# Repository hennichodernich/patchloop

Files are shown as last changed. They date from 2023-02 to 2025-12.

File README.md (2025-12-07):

# patchloop
Design files for the PatchLoop PCB

The files patchloop2.kicad_* contain the version with RJ45 jacks on opposite sides. This allows for neat short traces between the jacks.

I needed to rework the files patchloop.kicad_* (jacks on same side) because the first version contained a bug so that only one loop was used effectively.

PCB manufacturer Aisler will directly accept the KiCad file for manufacturing, but you can find zipfiles with the gerbers for both variants in the gerbers/ subdirectory. Any PCB manufacturer (e.g. BetaLayout, JLCPCB, PCBWay, OSHPark) should be able to accept those.

Licensed under CC BY-SA 3.0

# Note on the choice of balun

While in the schematic (and in the BOM) you will find an M/A-COM ETC4-1-2, this might not be the optimal choice for all possible patch cables. For cables with a length of 2-3 meters, an ETC1-1-13 usually works better to achieve ~50 ohms on the coax connector. The ETC4-1-2 is advantageous for very long cables (and thus higher impedances). I also tried Coilcraft WBC4-4 to transform from very low impedances to 50 ohms (take care of its orientation), but this only makes sense for very short cables: A 1m cable exposed approximately 10 ohms to my NanoVNA.

In general the same holds for selfwound baluns, an 1:1 balun will work best in most of your applications. For instance, I found 2:2 turns on a 9ct Fair-Rite 2843002402 binocular core working well.

Best overall performance including VLF and LF showed a M/A-COM ETC1-1T-2TR combined with 2m of S/FTP Cat6 cable.

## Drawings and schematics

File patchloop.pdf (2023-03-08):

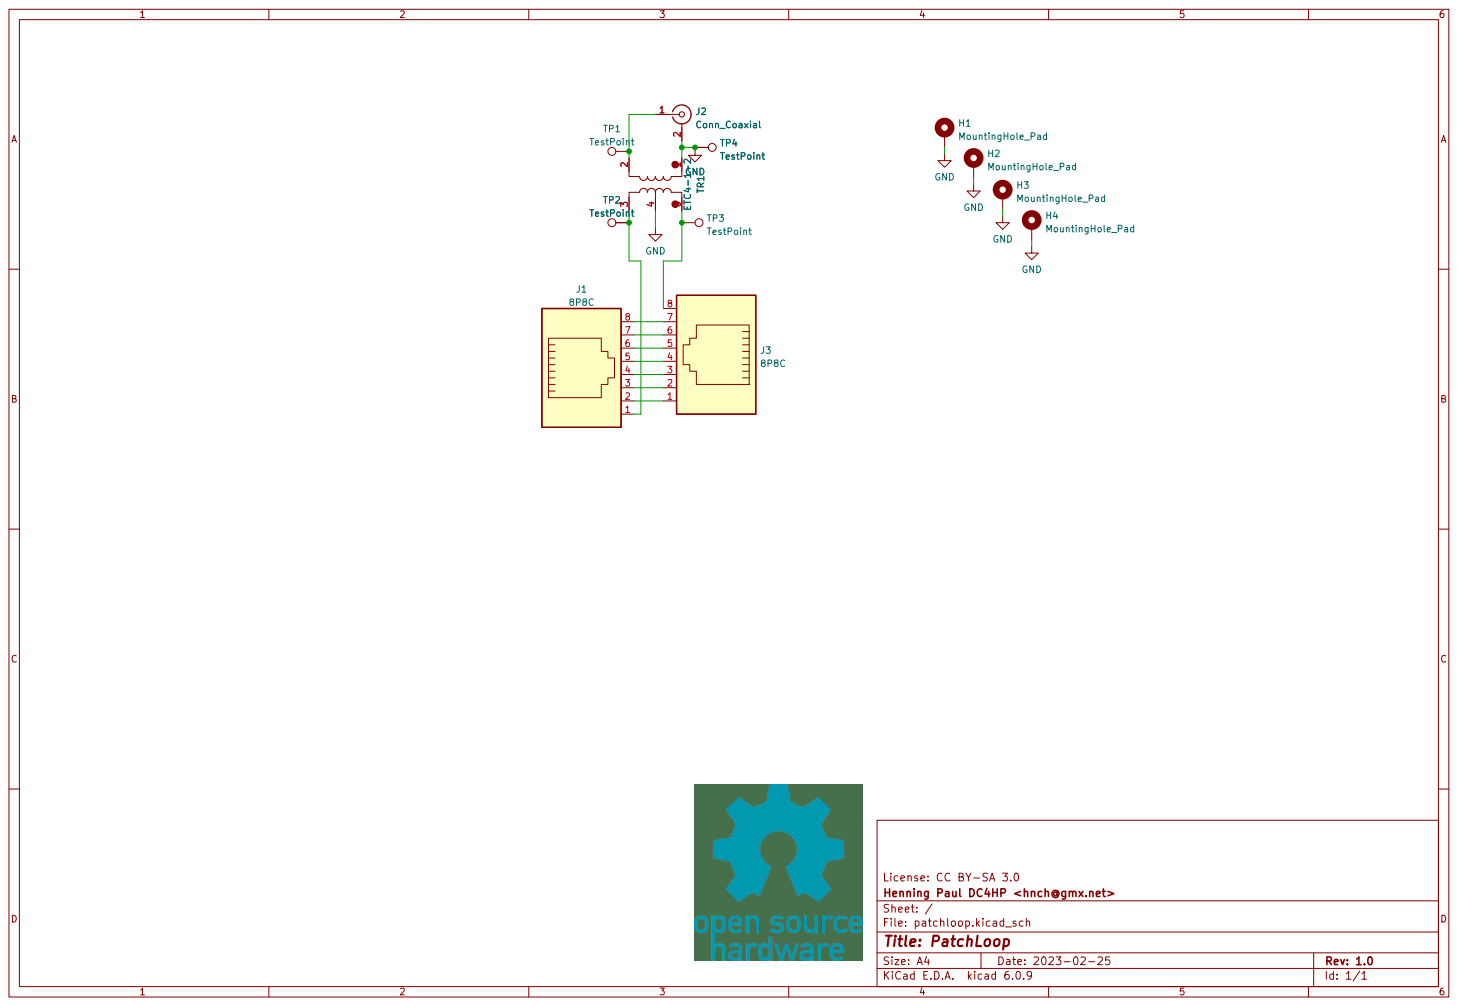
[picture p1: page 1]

License: CC BY-SA 3.0
File: patchloop.kicad_sch Sheet: / Henning Paul DC4HP <hnch@gmx.net>

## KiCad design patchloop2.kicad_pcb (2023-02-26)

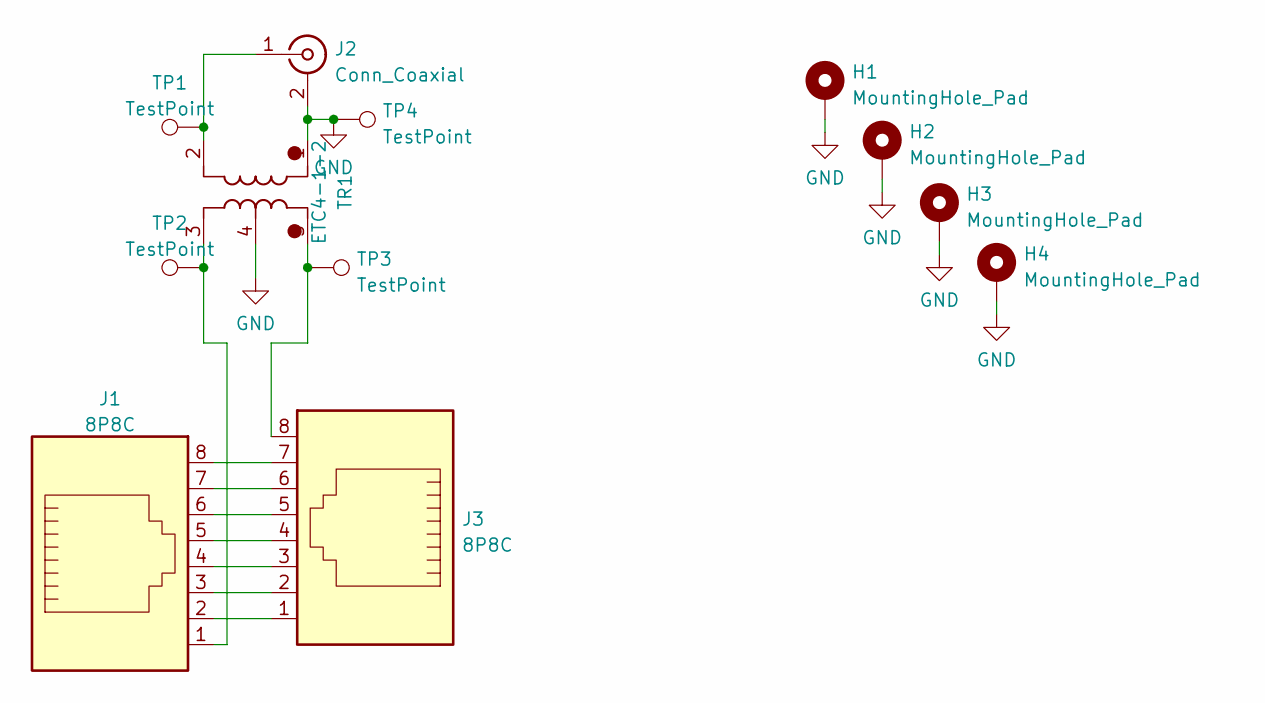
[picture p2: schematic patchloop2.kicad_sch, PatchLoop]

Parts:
H1, H2, H3, H4: MountingHole_Pad; MountingHole_3.2mm_M3_DIN965_Pad
J1, J3: 8P8C; RJ45_Amphenol_54602-x08_Horizontal
J2: Conn_Coaxial; SMA_Samtec_SMA-J-P-X-ST-EM1_EdgeMount
TP1, TP2, TP3, TP4: TestPoint; TestPoint_THTPad_D2.0mm_Drill1.0mm
TR1: ETC4-1-2; Transformer_MACOM_SM-22

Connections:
GND: H1.1, H2.1, H3.1, H4.1, J2.2 (Ext), TP4.1, TR1.1, TR1.4
unnamed: J1.1, TP2.1, TR1.3
unnamed: J1.2, J3.1
unnamed: J1.3, J3.2
unnamed: J1.4, J3.3
unnamed: J1.5, J3.4
unnamed: J1.6, J3.5
unnamed: J1.7, J3.6
unnamed: J1.8, J3.7
unnamed: J2.1 (In), TP1.1, TR1.2
unnamed: J3.8, TP3.1, TR1.5

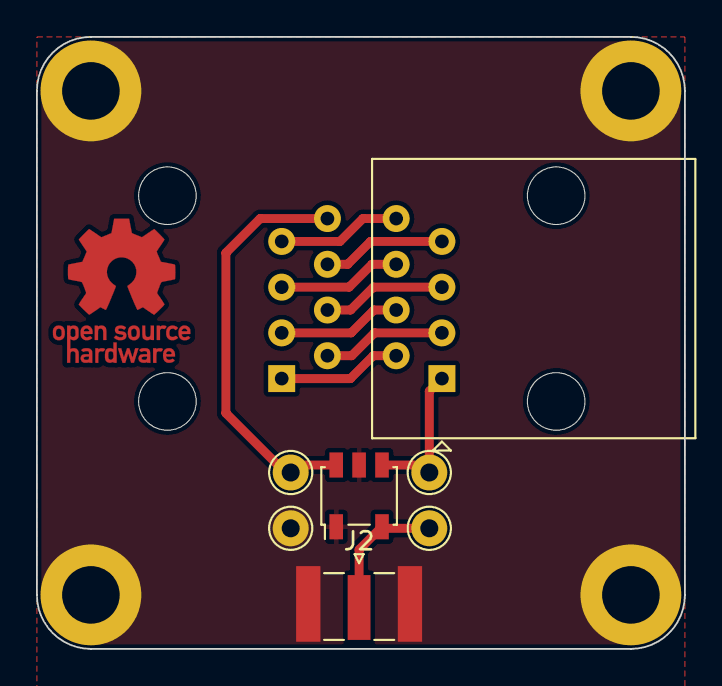
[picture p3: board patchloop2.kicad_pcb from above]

Board: 2 copper layers, 36.0 x 34.0 mm, 12 parts (1 on the bottom side), 11 nets.

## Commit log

2023-02-26 Removed non-working version
    [patchloop.kicad_pcb, patchloop.kicad_sch]
2023-02-26 Re-added corrected version with jacks on same side
    [patchloop.kicad_pcb, patchloop.kicad_sch]
2023-02-26 Minor beautification update
    [patchloop.kicad_pcb, patchloop.kicad_sch, patchloop2.kicad_pcb]
2023-02-26 Added zipfiles for Gerbers.
2023-03-08 Added schematic
